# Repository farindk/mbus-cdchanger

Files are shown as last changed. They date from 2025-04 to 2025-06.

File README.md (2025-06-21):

# M-Bus CD-Changer Controller

A controller board for standalone use of Alpine M-Bus CD-changers.

I got hold of an old car CD-changer that was originally built into a Mercedes-Benz car.
The car and the radio did not exist anymore, but since CD-changers are cool tech, I was wondering whether I could make it work again.
After some searching, I found that the actual manufacturer of the device is Alpine and that it is controlled by an M-Bus protocol.
The pinout of the connector apparently is proprietary, but it is not too difficult to identify the +12V / GND wires.
Just notice that there is a separate separate wire to the car ignition that also has to be connected to +12V to start it up.

The other wires are for M-Bus and the audio output, each with its own GND.

Fortunately, I found this website that did some reverse engineering of the M-Bus protocol: http://www.hohensohn.info/mbus/
Most of it matched my CD-changer, but several commands simply did not work, thus I could not implement typical CD-player functions like "pause".
I assume that this is a limitation of my specific device, but since I don't have the original radio controller, I cannot say for sure.

## Video

(https://www.youtube.com/watch?v=HMd5gL0tslU)

[Demo video](https://www.youtube.com/watch?v=HMd5gL0tslU)

## Building it

For anyone interested in playing along, this repository contains the KiCad files for the PCB. The schematics are basically the voltage-level adapter as shown on http://www.hohensohn.info/mbus/
plus the Atmel microcontroller with a few switches, HD44780 compatible display, and power supply. I use an old 12V plug-in power supply. Note that the PCB has the footprint for a TO-92 7805 regulator for the 5V needed for the uC and display.
However, the TO-92 was a slightly too optimistic choice. When I tried, it immediately dissolved in a white cloud. Thus, a TO-220 should be fitted into it instead.
The LCD used is this one: [PDF datasheet](https://www.lcd-module.de/eng/pdf/doma/dips082e.pdf).
The uC-Board is a cheap [Arduino clone](https://www.amazon.com/Teyleten-Robot-Bootloadered-Development-Microcontroller/dp/B08THVMQ46/).

Because of the minimum ordering quantities, I have a couple of spare PCBs (3 available). Anyone interested can drop me a line and I'll send it to them for postage and packaging.

I removed the suspension mounting of the CD drive since it was worn out after so many years anyways, and I mounted the drive mechanics directly to the case.



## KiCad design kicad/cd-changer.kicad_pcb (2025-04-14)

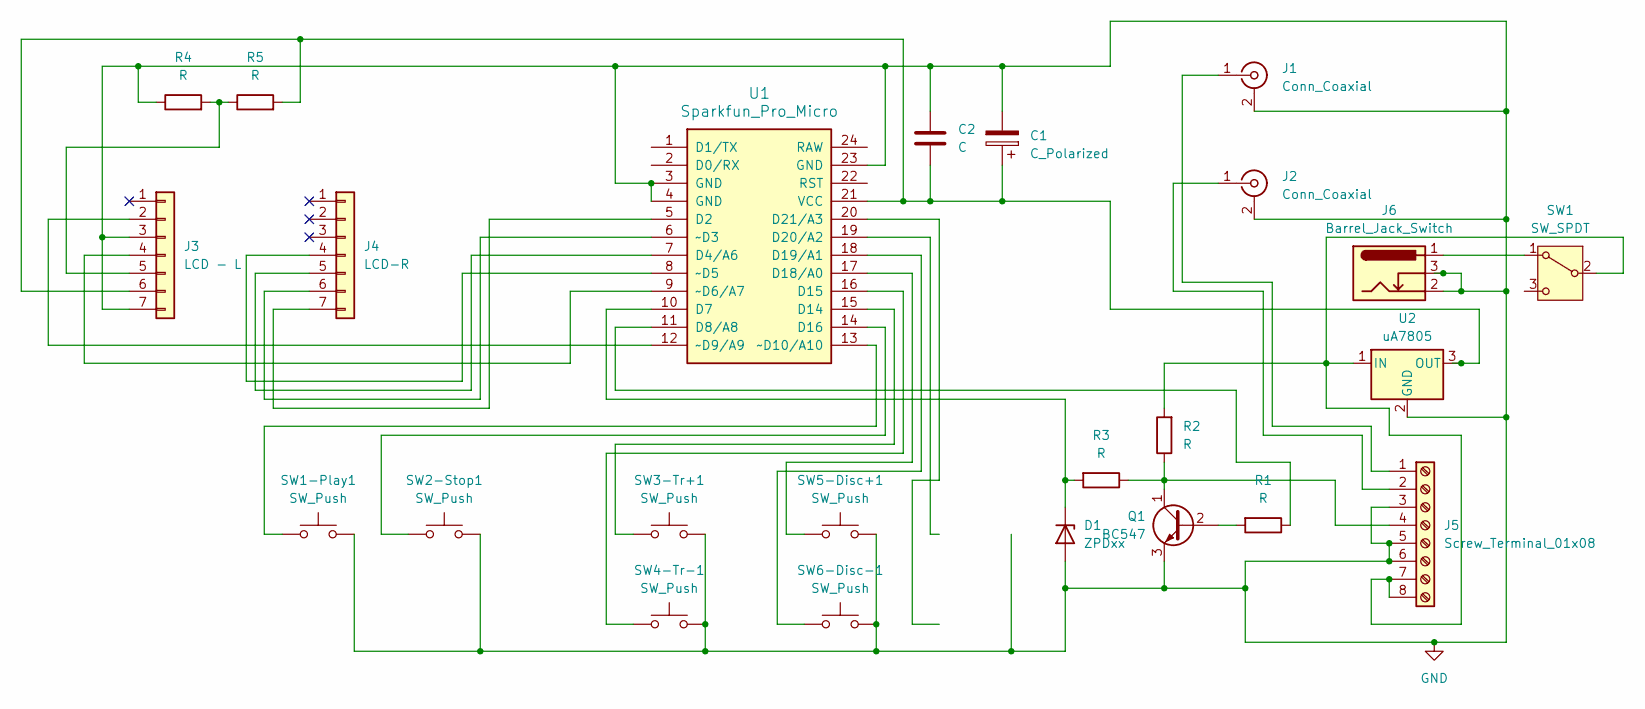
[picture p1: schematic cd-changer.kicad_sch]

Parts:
C1: C_Polarized; C_Radial_D10.0mm_H12.5mm_P5.00mm
C2: C; C_Disc_D7.5mm_W5.0mm_P5.00mm
D1: ZPDxx; D_DO-35_SOD27_P10.16mm_Horizontal
J1, J2: Conn_Coaxial; Cinch-Buchse
J3: LCD - L; PinHeader_1x07_P2.54mm_Vertical
J4: LCD-R; PinHeader_1x07_P2.54mm_Vertical
J5: Screw_Terminal_01x08; TerminalBlock_bornier-8_P5.08mm
J6: Barrel_Jack_Switch; BarrelJack_with_switch
Q1: BC547; TO-92_Inline
R1, R2, R3, R4, R5: R; R_Axial_DIN0204_L3.6mm_D1.6mm_P7.62mm_Horizontal
SW1: SW_SPDT; SW_Slide_3pin
SW1-Play1, SW2-Stop1, SW3-Tr+1, SW4-Tr-1, SW5-Disc+1, SW6-Disc-1: SW_Push; SW_PUSH_6mm_H8mm
U1: Sparkfun_Pro_Micro
U2: uA7805; TO-92L_HandSolder

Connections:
GND: C1.2, C2.1, D1.2 (A), J1.2 (Ext), J2.2 (Ext), J3.3, J3.7, J5.3, J5.5, J5.6, J6.2, J6.3, Q1.3 (E), R4.1, SW1-Play1.2, SW2-Stop1.2, SW3-Tr+1.2, SW4-Tr-1.2, SW5-Disc+1.2, SW6-Disc-1.2, U1.3 (GND), U1.4 (GND), U1.23 (GND), U2.2 (GND)
unnamed: D1.1 (K), R3.2, U1.10 (D7)
unnamed: J1.1 (In), J5.1
unnamed: J2.1 (In), J5.2
unnamed: J3.2, U1.12 (~D9/A9)
unnamed: J3.4, U1.9 (~D6/A7)
unnamed: J3.5, R4.2, R5.1
unnamed: C1.1, C2.2, J3.6, R5.2, U1.21 (VCC), U2.3 (OUT)
unnamed: J4.4, U1.8 (~D5)
unnamed: J4.5, U1.7 (D4/A6)
unnamed: J4.6, U1.6 (~D3)
unnamed: J4.7, U1.5 (D2)
unnamed: J5.4, Q1.1 (C), R2.1, R3.1
unnamed: J5.7, J5.8, R2.2, SW1.2 (B), U2.1 (IN)
unnamed: Q1.2 (B), R1.2
unnamed: J6.1, SW1.1 (A)
unnamed: R1.1, U1.11 (D8/A8)
unnamed: SW3-Tr+1.1, U1.15 (D14)
unnamed: SW4-Tr-1.1, U1.16 (D15)
unnamed: SW2-Stop1.1, U1.14 (D16)
unnamed: SW5-Disc+1.1, U1.17 (D18/A0)
unnamed: SW6-Disc-1.1, U1.18 (D19/A1)
unnamed: SW1-Play1.1, U1.13 (~D10/A10)

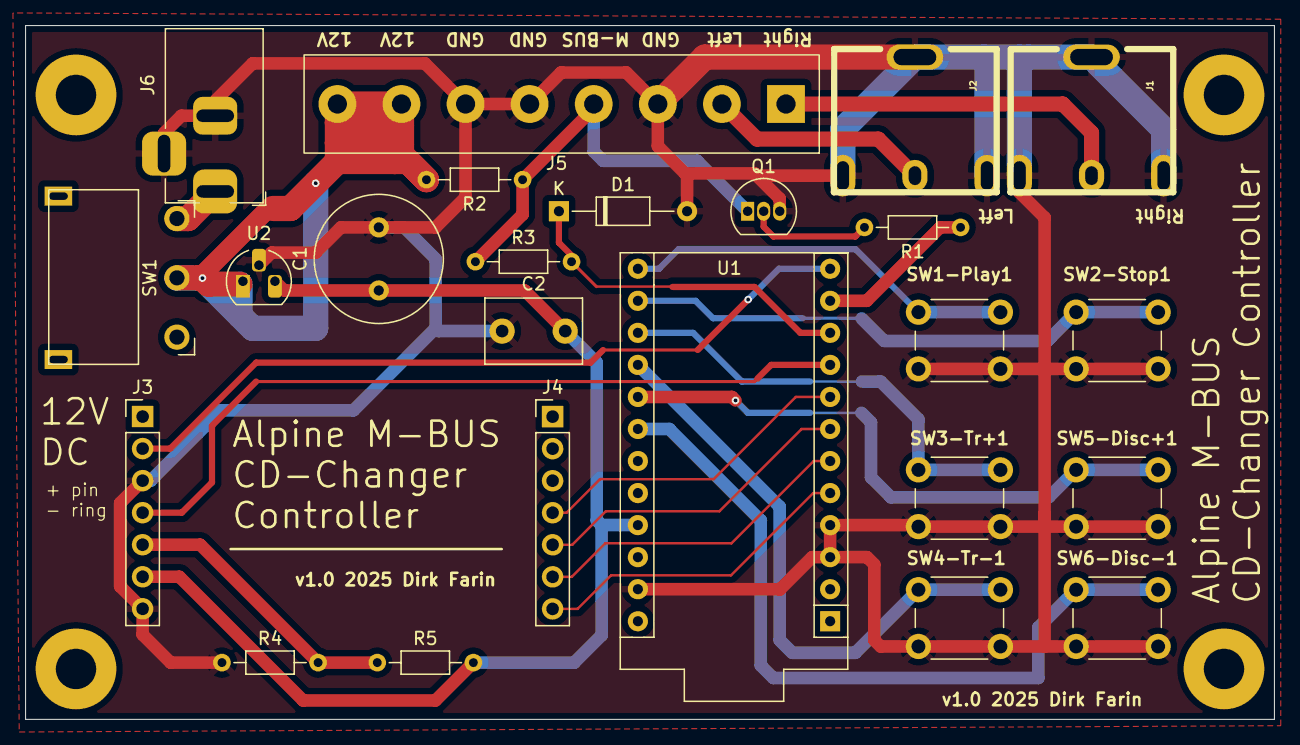
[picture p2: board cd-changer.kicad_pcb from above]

Board: 2 copper layers, 99.0 x 55.0 mm, 24 parts (0 on the bottom side), 23 nets.

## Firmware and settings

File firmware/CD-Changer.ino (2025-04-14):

/*
  Alpine M-Bus CD-changer controller.

  MIT License

  Copyright (c) 2025 Dirk Farin <dirk.farin@gmail.com>

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
  THE SOFTWARE IS PROVIDED "AS IS", WITHOUT WARRANTY OF ANY KIND, EXPRESS OR
  IMPLIED, INCLUDING BUT NOT LIMITED TO THE WARRANTIES OF MERCHANTABILITY,
  FITNESS FOR A PARTICULAR PURPOSE AND NONINFRINGEMENT. IN NO EVENT SHALL THE
  AUTHORS OR COPYRIGHT HOLDERS BE LIABLE FOR ANY CLAIM, DAMAGES OR OTHER
  LIABILITY, WHETHER IN AN ACTION OF CONTRACT, TORT OR OTHERWISE, ARISING FROM,
  OUT OF OR IN CONNECTION WITH THE SOFTWARE OR THE USE OR OTHER DEALINGS IN THE
  SOFTWARE.
*/


#include <LiquidCrystal.h>

const char* nibble = "0123456789abcdef";

// --- ISR

volatile unsigned long lastTime = 0;
volatile uint8_t mbus;

volatile uint8_t flushed = 1;
volatile uint8_t bits = 0;
volatile uint8_t nBits = 0;

volatile uint8_t ignore_input = 0;

volatile uint8_t input_buffer[256];
volatile uint8_t input_ptr = 0;

// --- main thread

uint8_t command[16];
uint8_t commandLength = 0;

const uint8_t commandLengthTable[16] = {
  1, 1, 1, 1, 1, 1, 1, 1,
  2, 15, 12, 11, 12, 10, 9, 7
};

struct cd_time {
  uint8_t track;

  uint8_t min10, min01;
  uint8_t sec10, sec01;

  void serialPrint_track() {
    Serial.print((int)(track));
  }

  void serialPrint_time() {
    Serial.write('0' + min10);
    Serial.write('0' + min01);
    Serial.write(':');
    Serial.write('0' + sec10);
    Serial.write('0' + sec01);
  }
};

struct cd_info : public cd_time {
  bool known = false;
  bool empty = false;
};

cd_info cdinfo[6];

uint8_t current_disk = 1;
uint8_t current_track = 1;

uint8_t selected_disk = 1;
uint8_t selected_track = 1;

cd_time current_time;

enum class State {
  Loading,
  Failure_NoDisc,
  Stopped_Info,
  Stopped_Select,
  Playing_Info,
  Playing_Select
};

volatile State state = State::Stopped_Info;

LiquidCrystal lcd(6, 9, 5,4,3,2);

byte char_play[8] = {
  B11000,
  B11100,
  B11110,
  B11111,
  B11110,
  B11100,
  B11000,
  B00000
};

byte char_pause[8] = {
  B11011,
  B11011,
  B11011,
  B11011,
  B11011,
  B11011,
  B11011,
  B00000
};

byte char_stop[8] = {
  B00000,
  B11111,
  B11111,
  B11111,
  B11111,
  B11111,
  B00000,
  B00000
};

byte char_empty[8] = {
  B00000,
  B01110,
  B10001,
  B10101,
  B10001,
  B01110,
  B00000,
  B00000
};

byte char_full[8] = {
  B00000,
  B01110,
  B11111,
  B11011,
  B11111,
  B01110,
  B00000,
  B00000
};

byte char_rot[4][8] = { { B00000,
                          B01110,
                          B11101,
                          B11001,
                          B11111,
                          B01110,
                          B00000,
                          B00000 },
                        { B00000,
                          B01110,
                          B11111,
                          B11011,
                          B11001,
                          B01110,
                          B00000,
                          B00000 },
                        { B00000,
                          B01110,
                          B11111,
                          B10011,
                          B10111,
                          B01110,
                          B00000,
                          B00000 },
                        { B00000,
                          B01110,
                          B10011,
                          B11011,
                          B11111,
                          B01110,
                          B00000,
                          B00000 } };

byte char_unknown[8] = {
  B00000,
  B00000,
  B00100,
  B01110,
  B00100,
  B00000,
  B00000,
  B00000
};

byte char_ellipsis[8] = {
  B00000,
  B00000,
  B00000,
  B00000,
  B00000,
  B00000,
  B10101,
  B00000
};



void output_nibble() {
  char c = nibble[bits];

  if (input_ptr < 256) {
    input_buffer[input_ptr++] = bits;
  }

  bits = 0;
  nBits = 0;
  flushed = 0;
}

void flush_bits() {
  nBits = 0;
  bits = 0;
}

void add_bit(uint8_t b) {
  bits <<= 1;
  bits |= b;
  nBits++;

  if (nBits == 4) {
    output_nibble();
  }
}

void isr7() {
  if (ignore_input) {
    return;
  }

  unsigned long time = micros();
  unsigned long duration = time - lastTime;
  lastTime = time;

  if (mbus == LOW) {
    if (duration > (unsigned long)400 && duration < (unsigned long)1000) {
      add_bit(0);
    } else if (duration > (unsigned long)1400 && duration < (unsigned long)2400) {
      add_bit(1);
    }
  }

  if (mbus == HIGH && duration > (unsigned long)4000) {
    input_ptr = 0;
    nBits = 0;
    bits = 0;
  }

  mbus = digitalRead(7);
}

void setup() {
  lastTime = micros();

  pinMode(7, INPUT);
  pinMode(8, OUTPUT);
  digitalWrite(8, LOW);

  pinMode(10, INPUT_PULLUP);
  pinMode(16, INPUT_PULLUP);
  pinMode(15, INPUT_PULLUP);
  pinMode(14, INPUT_PULLUP);
  pinMode(18, INPUT_PULLUP);
  pinMode(19, INPUT_PULLUP);
  pinMode(20, INPUT_PULLUP);
  pinMode(21, INPUT_PULLUP);

  lcd.begin(8, 2);
  lcd.clear();
  delay(100);
  //lcd.print("Hello\0");

  lcd.createChar(1, char_play);
  lcd.createChar(2, char_pause);
  lcd.createChar(3, char_ellipsis);
  lcd.createChar(4, char_empty);
  lcd.createChar(5, char_full);
  lcd.createChar(6, char_rot[0]);
  lcd.createChar(7, char_unknown);
  lcd.setCursor(0, 1);
  lcd.write(1);
  lcd.write(2);
  lcd.write(3);
  lcd.write(4);
  lcd.write(5);
  lcd.write(6);
  lcd.write(7);

  mbus = digitalRead(7);

  attachInterrupt(digitalPinToInterrupt(7), isr7, CHANGE);
}

#define CHAR_PLAY 1
#define CHAR_PAUSE 2
#define CHAR_STOP 3
#define CHAR_ELLIPSIS 3

#define CHAR_EMPTY 4
#define CHAR_FULL 5
#define CHAR_ROTATING 6
#define CHAR_UNKNOWN 7

uint16_t cnt = 0;
uint8_t led = 0;
uint8_t checksum = 0;

void transmit_nibble(uint8_t v) {

  ignore_input = 1;

  int i;
  for (i = 0; i < 4; i++) {
    unsigned long startTime = micros();
    digitalWrite(8, HIGH);  // this is inverted
    unsigned long onTime = (v & 0x8) ? 1800 : 600;

    for (;;) {
      unsigned long now = micros();
      unsigned long duration = now - startTime;
      if (duration >= onTime) {
        break;
      }
    }

    digitalWrite(8, LOW);  // this is inverted

    for (;;) {
      unsigned long now = micros();
      unsigned long duration = now - startTime;
      if (duration >= 3000) {
        break;
      }
    }

    v <<= 1;
  }

  ignore_input = 0;

  lastTime = micros();
}


uint8_t cmd_buf[20];
uint8_t queued_command_length = 0;

#define FLAG_PLAY 1
#define FLAG_PAUSE 2
#define FLAG_RANDOM 4
#define FLAG_STOP 0x40

void send_queued_command() {
  for (int i = 0; i < queued_command_length; i++) {
    transmit_nibble(cmd_buf[i]);
  }

  queued_command_length = 0;
}

void send_nibble(uint8_t v) {
  cmd_buf[queued_command_length++] = v;
  checksum ^= v;
}

void send_ping() {
  checksum = 0;
  send_nibble(1);
  send_nibble(8);
  send_nibble(checksum + 1);
}

void send_set_disk(uint8_t disk, uint8_t track, uint8_t flags) {
  checksum = 0;
  send_nibble(1);
  send_nibble(1);
  send_nibble(3);
  send_nibble(disk);
  send_nibble(track / 10);
  send_nibble(track % 10);
  send_nibble(flags >> 4);
  send_nibble(flags & 0xF);
  send_nibble(checksum + 1);
}

void send_play_state(uint8_t flags) {
  checksum = 0;
  send_nibble(1);
  send_nibble(1);
  send_nibble(1);
  send_nibble(flags >> 4);
  send_nibble(flags & 0xF);
  send_nibble(checksum + 1);
}

void process_command() {
  if (commandLength < 3) {
    commandLength = 0;
    return;
  }

  // check checksum

  uint8_t checksum = 0;
  for (int i = 0; i < commandLength - 1; i++) {
    checksum ^= command[i];
  }
  checksum = (checksum + 1) & 0xF;

  if (checksum != command[commandLength - 1]) {
    Serial.print("INVALID CHECKSUM ");
    Serial.print(nibble[checksum]);
    Serial.print(":");
    Serial.println(nibble[command[commandLength - 1]]);
    commandLength = 0;
    return;
  }

  /*
  Serial.print("CMD: ");
  for (int i=0;i<commandLength;i++) {
    Serial.print(nibble[command[i]]);
  }
  Serial.println("");
  */
  
  if (commandLength == 16 && command[0] == 9 && command[1] == 9) {
    cd_time t = current_time;
    t.track = (command[3] * 10 + command[4]);
    t.min10 = command[7];
    t.min01 = command[8];
    t.sec10 = command[9];
    t.sec01 = command[10];
    uint8_t index = (command[5] * 10) + command[6];
    uint8_t flags3 = command[14];

    /*
    Serial.print("track: ");
    t.serialPrint_track();
    Serial.print(" time: ");
    t.serialPrint_time();
    Serial.print('\n');
    */
    
    if (flags3 & FLAG_PLAY) {
    }

    if (flags3 & 0x02) {
      state = State::Stopped_Info;
    } else if (state == State::Playing_Select) {
      // NOP, stay in this state
    } else {
      state = State::Playing_Info;
    }

    if (t.track != 0) {
      current_track = t.track;
      current_time = t;
    }
  } else if (commandLength == 13 && command[0] == 9 && command[1] == 0x0c) {
    uint8_t disk = command[2];

    if (disk >= 1 && disk <= 6) {
      cd_info& info = cdinfo[disk - 1];

      info.track = (command[5] * 10 + command[6]);
      info.min10 = command[7];
      info.min01 = command[8];
      info.sec10 = command[9];
      info.sec01 = command[10];

      info.known = true;
      info.empty = false;

      current_disk = disk;
      selected_disk = disk;

      /*
      Serial.print("diskinfo: ");
      Serial.write('0' + disk);
      Serial.print(" track: ");
      info.serialPrint_track();
      Serial.print(" time: ");
      info.serialPrint_time();
      Serial.print('\n');
      */
    }
  } else if (commandLength == 12 && command[0] == 9 && command[1] == 0x0b) {
    uint8_t disk = command[3];
    uint8_t status = command[2];
    if (disk >= 1 && disk <= 6) {

      if (status == 0x0d) {
        if (!cdinfo[disk - 1].known) {
          cdinfo[disk - 1].known = true;
          cdinfo[disk - 1].empty = true;
        }
      } else if (status == 0x09) {
        cdinfo[disk - 1].known = true;
        cdinfo[disk - 1].empty = false;
      }
    }

    if (status == 0x0a) {
      for (int i = 0; i < 6; i++) {
        cdinfo[i].known = false;
        cdinfo[i].empty = false;
      }
    }

    /*
    Serial.print("changing disk: ");
    Serial.write('0' + disk);
    Serial.print(" state: ");
    Serial.write(nibble[command[2]]);
    Serial.print('\n');
    */
    
    current_disk = disk;

    // ejecting: 9 d 8 a
    // inserting: b c d  (unsuccessful / empty)
    // inserting: b c 8 9 (successful)
  }

  // 9ba10020022c   // eject ?

  commandLength = 0;
}

char blinking(char on, char off, bool enable) {
  if (!enable) {
    return on;
  }

  unsigned long t = millis();
  if ((t / 256) % 2) {
    return on;
  } else {
    return off;
  }
}

void lcdWriteTrack(uint8_t track, bool blink) {
  if (track < 10) {
    lcd.write(' ');
  } else {
    lcd.write(blinking('0' + track/10, ' ', blink));
  }

  lcd.write(blinking('0' + track%10, ' ', blink));
}

void lcdWriteTime(const cd_time& cd, bool blink) {
  if (cd.min10 == 0) {
    lcd.write(' ');
  } else {
    lcd.write(blinking('0' + cd.min10, ' ', blink));
  }

  lcd.write(blinking('0' + cd.min01, ' ', blink));
  lcd.write(':');
  lcd.write(blinking('0' + cd.sec10, ' ', blink));
  lcd.write(blinking('0' + cd.sec01, ' ', blink));
}

char* string_loading = "Loading ";

void update_display()
{
  lcd.setCursor(0, 0);
  if (state == State::Loading) {
    string_loading[7] = CHAR_ELLIPSIS;
    lcd.print(string_loading);
  } else if (state == State::Failure_NoDisc) {
    lcd.print("No disc ");
  } else if (state == State::Stopped_Info) {
    const cd_info& cd = cdinfo[selected_disk - 1];
    if (cd.known && !cd.empty) {
      lcdWriteTrack(cd.track, false);
      lcd.write(' ');
      lcdWriteTime(cd, false);
    } else {
      lcd.print(" - --:--");
    }
  } else if (state == State::Stopped_Select || state == State::Playing_Select) {
    const cd_info& cd = cdinfo[selected_disk - 1];
    if (cd.known && !cd.empty) {
      lcdWriteTrack(selected_track, true);
      lcd.write('/');
      lcdWriteTrack(cd.track, false);
      lcd.print("   ");
    } else {
      lcd.print(" - --:--");
    }
  } else if (state == State::Playing_Info) {
    const cd_info& cd = cdinfo[current_disk - 1];
    if (cd.known && !cd.empty) {
      lcdWriteTrack(current_time.track, false);
      lcd.write(' ');
      lcdWriteTime(current_time, false);
    } else {
      lcd.print(" - --:--");
    }
  }

  // -------------------------

  lcd.setCursor(0, 1);
  if (state == State::Playing_Info || state == State::Playing_Select) {
    lcd.write(CHAR_PLAY);
  } else {
    lcd.write(' ');
  }

  lcd.write(' ');

  bool disk_blinking = (state == State::Loading || state == State::Stopped_Info || state == State::Stopped_Select || state == State::Playing_Select);
  for (int i = 0; i < 6; i++) {
    if (!cdinfo[i].known) {
      lcd.write(blinking(CHAR_UNKNOWN, ' ', disk_blinking && selected_disk == i + 1));
    } else if (cdinfo[i].empty) {
      lcd.write(blinking(CHAR_EMPTY, ' ', disk_blinking && selected_disk == i + 1));
    } else {
      char d = ((state == State::Playing_Info || state == State::Playing_Select) && current_disk == i+1) ? CHAR_ROTATING : CHAR_FULL;
      lcd.write(blinking(d, ' ', disk_blinking && selected_disk == i + 1));
    }
  }
}

void loop() {
  // put your main code here, to run repeatedly:

  unsigned long t = millis();

  uint8_t rotation_state = (t / 256) % 4;
  static uint8_t last_rotation_state = 0;
  if (rotation_state != last_rotation_state) {
    lcd.createChar(6, char_rot[rotation_state]);
    last_rotation_state = rotation_state;
  }

  update_display();

  noInterrupts();

  unsigned long now = micros();
  unsigned long duration = now - lastTime;


  while (input_ptr > 0 && input_buffer[0] != 9) {
    memmove(input_buffer, input_buffer + 1, input_ptr - 1);
    input_ptr--;
  }

  if (input_ptr >= 3) {
    uint8_t len = commandLengthTable[input_buffer[1]] + 1; // +1 for checksum
    if (input_ptr >= len) {
      memcpy(command, input_buffer, len);
      memmove(input_buffer, input_buffer + len, input_ptr - len);
      input_ptr -= len;
      commandLength = len;
    }
  }

  interrupts();

  if (commandLength > 0) {
    process_command();
  }

  if (mbus == HIGH && duration > (unsigned long)(20000UL)) {
    if (queued_command_length > 0) {
      send_queued_command();
    }
  }

  bool btn_play = (digitalRead(10) == LOW);
  bool btn_stop = (digitalRead(16) == LOW);
  bool btn_next_track = (digitalRead(14) == LOW);
  bool btn_prev_track = (digitalRead(15) == LOW);
  bool btn_next_disk = (digitalRead(18) == LOW);
  bool btn_prev_disk = (digitalRead(19) == LOW);

  bool all_released = !btn_play && !btn_stop && !btn_next_track && !btn_prev_track;
  static bool wait_for_release = false;

  if (wait_for_release) {
    wait_for_release = !all_released;
    if (wait_for_release == false) {
      delay(200);
    }
  } else if (btn_play) {
    wait_for_release = true;
    delay(200);

    if (state == State::Playing_Select) {
      state = State::Playing_Info;
    }

    if (cdinfo[selected_disk-1].known && cdinfo[selected_disk-1].empty) {
      return;
    }

    send_set_disk(selected_disk, selected_track, 0x10);
  } else if (btn_stop) {
    static uint8_t flagcnt = 0x01;

    send_set_disk(current_disk, 0, 0x20);
    delay(200);
    wait_for_release = true;
  } else if (btn_next_track) {
    const cd_info& cd = cdinfo[selected_disk - 1];
    if (!cd.known) return;

    if (selected_track < cd.track) {
      selected_track++;
      delay(200);
      wait_for_release = true;
    }

      if (state == State::Stopped_Info) {
        state = State::Stopped_Select;
      }
      else if (state == State::Playing_Info) {
        state = State::Playing_Select;
      }
  } else if (btn_prev_track) {
    const cd_info& cd = cdinfo[selected_disk - 1];
    if (!cd.known) return;

    if (selected_track > 1) {
      selected_track--;
      delay(200);
      wait_for_release = true;
    }

      if (state == State::Stopped_Info) {
        state = State::Stopped_Select;
      }
      else if (state == State::Playing_Info) {
        state = State::Playing_Select;
      }
  } else if (btn_next_disk) {
    if (selected_disk < 6) {
      selected_disk++;
      delay(200);
      wait_for_release = true;

      if (cdinfo[selected_disk - 1].empty) {
        selected_track = 1;
      }
      else {
        uint8_t nTracks = cdinfo[selected_disk - 1].track;
        if (selected_track > nTracks) {
          selected_track = nTracks;
        }
      }

      if (state == State::Playing_Info) {
        state = State::Playing_Select;
      }
    }
  } else if (btn_prev_disk) {
    if (selected_disk > 1) {
      selected_disk--;
      delay(200);
      wait_for_release = true;

      if (cdinfo[selected_disk - 1].empty) {
        selected_track = 1;
      }
      else {
        uint8_t nTracks = cdinfo[selected_disk - 1].track;
        if (selected_track > nTracks) {
          selected_track = nTracks;
        }
      }

      if (state == State::Playing_Info) {
        state = State::Playing_Select;
      }
    }
  }
}
